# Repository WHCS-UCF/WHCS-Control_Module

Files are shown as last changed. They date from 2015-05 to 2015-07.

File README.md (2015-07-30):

# WHCS Control Module Design

The EAGLE source files for WHCS' control module.

## Requirements
EAGLE

## Board Front
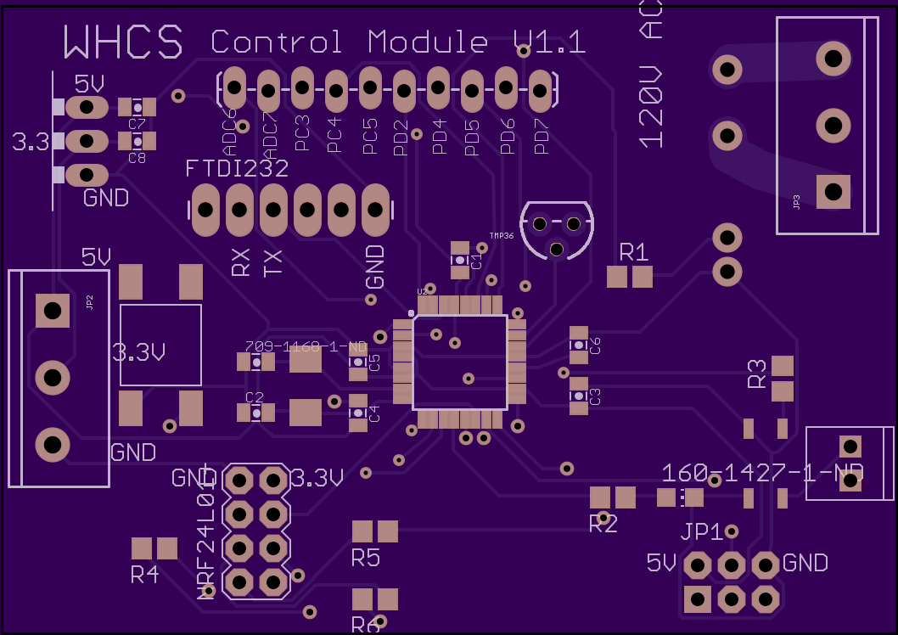
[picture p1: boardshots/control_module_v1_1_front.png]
Board Front


## Board Back
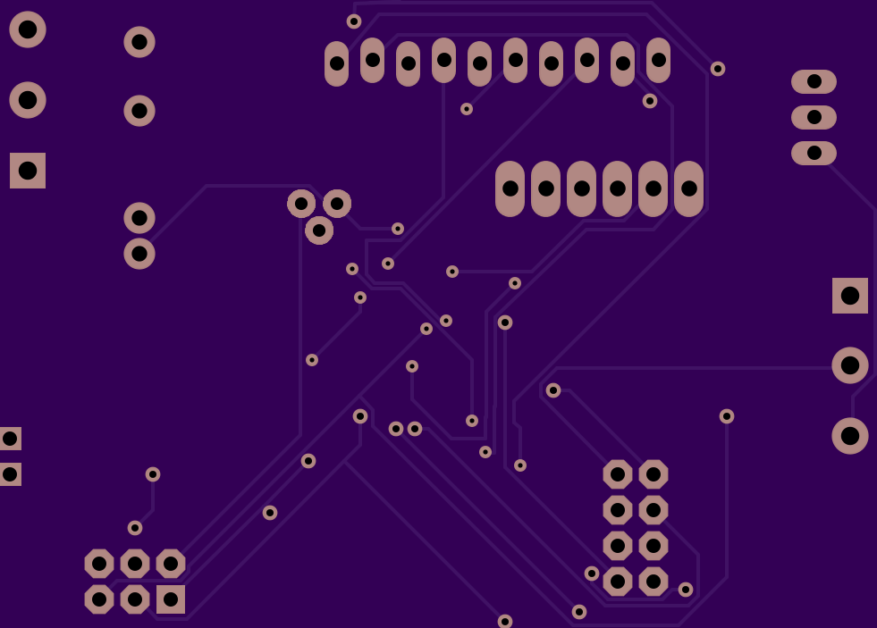
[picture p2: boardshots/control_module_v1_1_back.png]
Board Back


### Author
Jimmy Campbell<br/>
*Computer Engineer*

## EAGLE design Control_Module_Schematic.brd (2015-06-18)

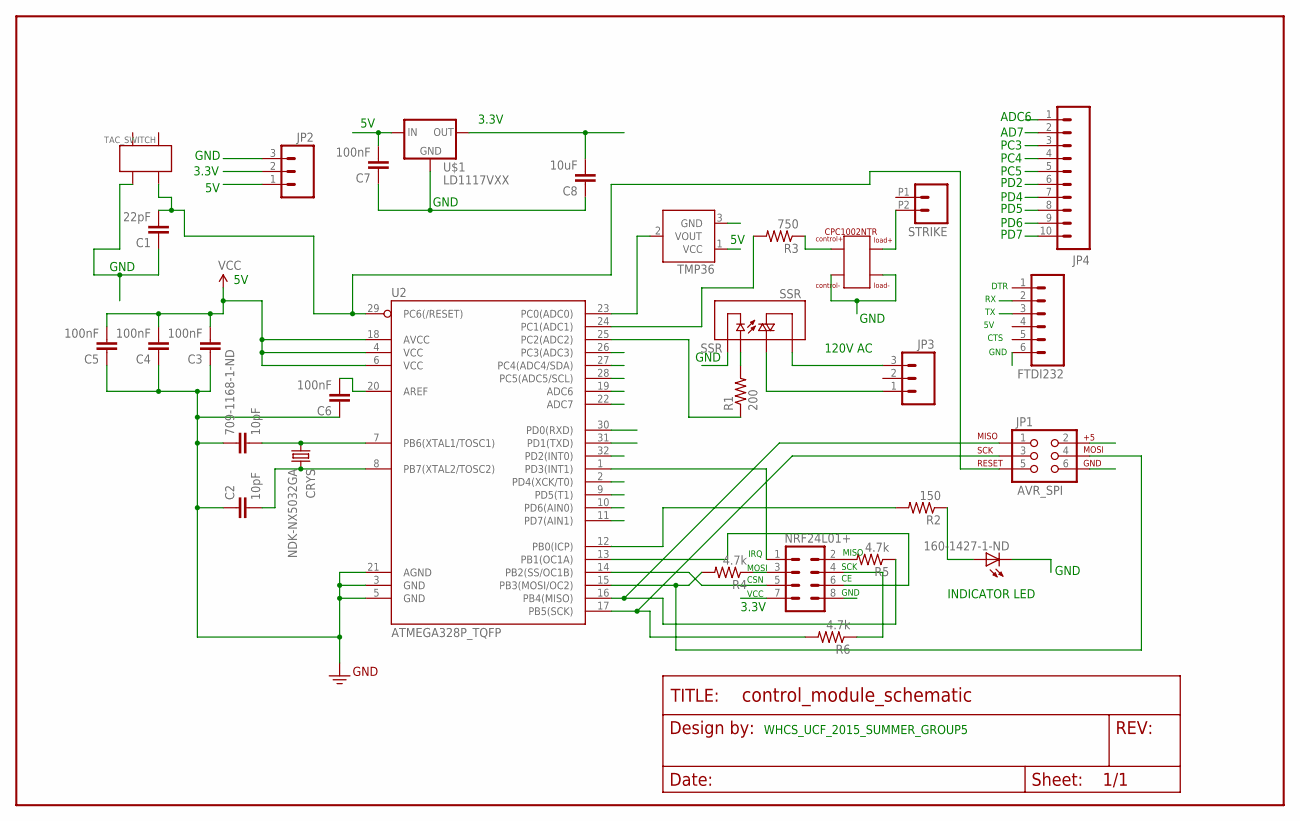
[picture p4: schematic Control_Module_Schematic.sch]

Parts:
160-1427-1-ND: LEDCHIP-LED0805; CHIP-LED0805
709-1168-1-ND: 10pF; 0805-CAP
C1: 22pF; 0805-CAP
C2: 10pF; 0805-CAP
C3, C4, C5, C6, C7: 100nF; 0805-CAP
C8: 10uF; 0805-CAP
CPC1002NTR: CPC1002NTR; CPC1002N
CRYS: NDK-NX5032GA; CRYS-5X3.2
FRAME1: FRAME-LETTERNO_PACKAGE; DUMMY
FTDI232: M06LONGPADS; 1X06_LONGPADS
JP1: AVR_SPI; 2X3-NS
JP2, JP3: M03-SCREW-5MM; SCREWTERMINAL-5MM-3
JP4: M10LOCK_LONGPADS; 1X10_LOCK_LONGPADS
NRF24L01+: M04X2; 2X4
R1: 200; R0805
R2: 150; R0805
R3: 750; R0805
R4, R5, R6: 4.7k; R0805
SSR: SSR; RELAY-S116S02F
STRIKE: M022.54MM_SCREWTERM; 1X02_2.54_SCREWTERM
TAC_SWITCH: TACTILE_SWITCH; TAC_SWITCH_GULL_WING
TMP36: TMP36TO-92-KIT; TO-92-KIT
U2: ATMEGA328P_TQFP; TQFP32-08
U$1: LD1117VXX; 78XXL

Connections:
3.3V: C8.2, JP2.2, NRF24L01+.7, U$1.OUT
5V: C3.2, C4.2, C5.2, C7.2, JP1.2, JP2.1, TMP36.1 (VCC), U2.4 (VCC), U2.6 (VCC), U2.18 (AVCC), U$1.IN
ADC6: JP4.1, U2.19 (ADC6)
ADC7: JP4.2, U2.22 (ADC7)
GND: 160-1427-1-ND.C, 709-1168-1-ND.1, C1.1, C2.1, C3.1, C4.1, C5.1, C6.1, C7.1, C8.1, CPC1002NTR.P$1, CPC1002NTR.P$4, FTDI232.6, JP1.6, JP2.3, NRF24L01+.8, SSR.P$4 (-), TAC_SWITCH.P$2, TMP36.3 (GND), U2.3 (GND), U2.5 (GND), U2.21 (AGND), U$1.GND
unnamed: NRF24L01+.5, U2.14 (PB2(SS/OC1B))
unnamed: JP1.1, R5.1, U2.16 (PB4(MISO))
unnamed: JP1.4, R4.2, U2.15 (PB3(MOSI/OC2))
unnamed: JP1.3, R6.2, U2.17 (PB5(SCK))
unnamed: NRF24L01+.1, U2.1 (PD3(INT1))
unnamed: NRF24L01+.6, U2.13 (PB1(OC1A))
unnamed: TMP36.2 (VOUT), U2.23 (PC0(ADC0))
unnamed: R1.2, SSR.P$3 (+)
unnamed: R1.1, U2.25 (PC2(ADC2))
unnamed: JP3.3, SSR.P$1 (T1)
unnamed: JP3.1, SSR.P$2 (T2)
unnamed: R3.2, U2.24 (PC1(ADC1))
unnamed: CPC1002NTR.P$2 (CONTROL+), R3.1
unnamed: 709-1168-1-ND.2, CRYS.P$1 (1), U2.7 (PB6(XTAL1/TOSC1))
unnamed: C2.2, CRYS.P$2 (2), U2.8 (PB7(XTAL2/TOSC2))
unnamed: R2.2, U2.12 (PB0(ICP))
unnamed: 160-1427-1-ND.A, R2.1
unnamed: CPC1002NTR.P$3, STRIKE.P2 (2)
unnamed: NRF24L01+.3, R4.1
unnamed: NRF24L01+.2, R5.2
unnamed: NRF24L01+.4, R6.1
unnamed: C6.2, U2.20 (AREF)
unnamed: C1.2, JP1.5, TAC_SWITCH.P$4, U2.29 (PC6(/RESET))
PC3: JP4.3, U2.26 (PC3(ADC3))
PC4: JP4.4, U2.27 (PC4(ADC4/SDA))
PC5: JP4.5, U2.28 (PC5(ADC5/SCL))
PD2: JP4.6, U2.32 (PD2(INT0))
PD4: JP4.7, U2.2 (PD4(XCK/T0))
PD5: JP4.8, U2.9 (PD5(T1))
PD6: JP4.9, U2.10 (PD6(AIN0))
PD7: JP4.10, U2.11 (PD7(AIN1))
RXD: FTDI232.3, U2.30 (PD0(RXD))
TXD: FTDI232.2, U2.31 (PD1(TXD))

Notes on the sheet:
IRQ
MOSI
CSN
VCC
MISO
SCK
GND
120V AC
3.3V
INDICATOR LED
DTR
CTS
ADC6
AD7
PC3
PC4
PC5
PD2
PD4
PD5
PD6
PD7
WHCS_UCF_2015_SUMMER_GROUP5

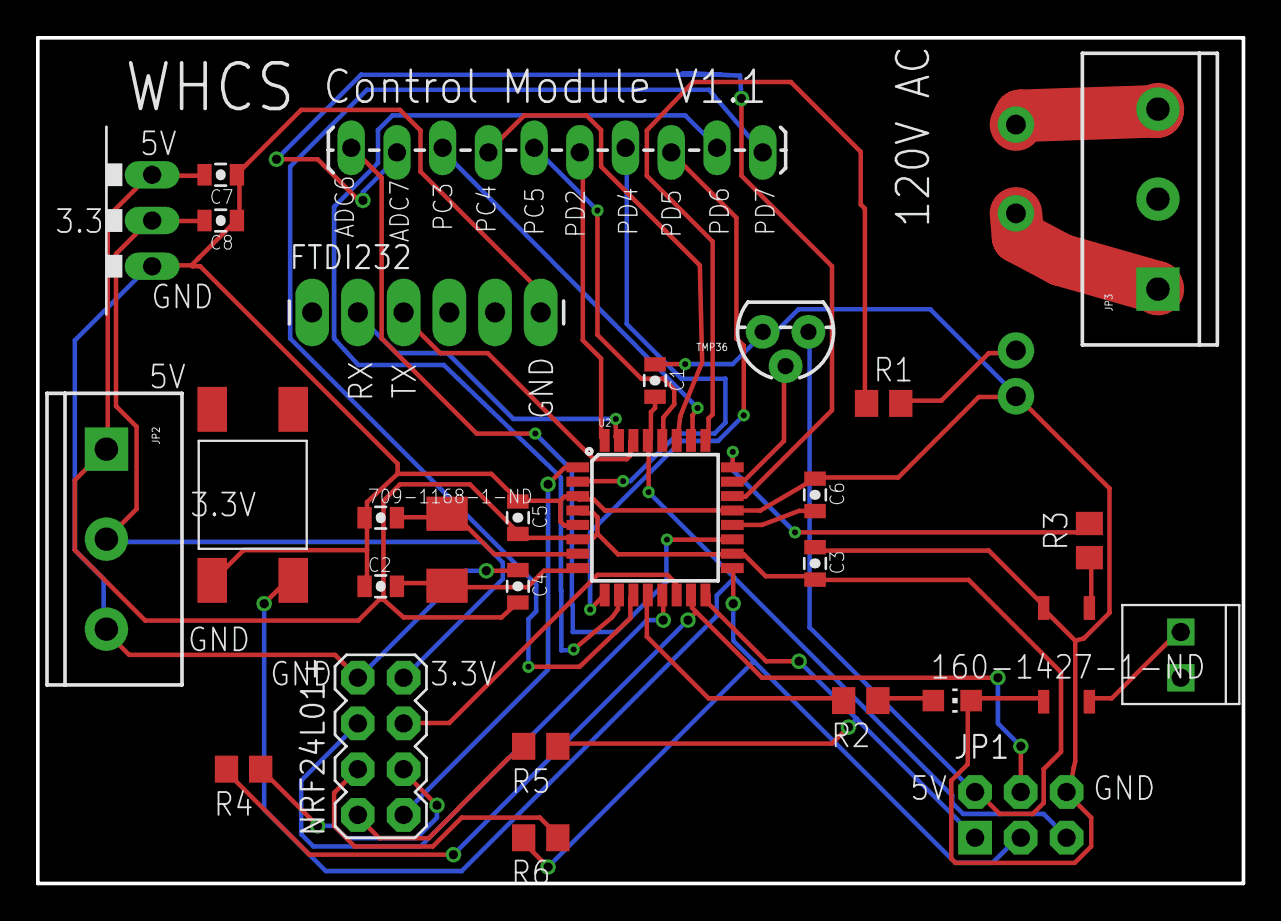
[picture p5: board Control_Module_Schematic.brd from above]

Board: 2 copper layers, 67.0 x 47.0 mm, 31 parts (0 on the bottom side), 38 nets.

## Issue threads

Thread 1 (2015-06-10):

Electronic strike solid state relay

jimmypc92, 2015-06-10:
The SSR for the electronic strike is connected to the ADC6 pin on the ATMEGA328P. This pin is not capable of providing output. The workaround for this is directly soldering a jumper wire on the board to the resistor that is connected to the ADC6 pin.

This is a big issue and should be fixed before any more orders are made.

Closed 2015-06-10.

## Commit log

2015-05-22 Made the layout for the board.
    [Control_Module_Schematic.brd, Control_Module_Schematic.sch]
2015-05-26 Board status when first submitted.
    This is the way the board was when first submitted to Oshpark for an
    initial run.
    [Control_Module_Schematic.brd, Control_Module_Schematic.sch]
2015-05-29 fixed drc fail. Two vias were too close together at the top right of the mcu
    [Control_Module_Schematic.brd, Control_Module_Schematic.sch]
2015-06-10 Changed the pin that controls the door strike
    [Control_Module_Schematic.brd, Control_Module_Schematic.sch]
2015-06-10 Enhanced crystal footprint
    Also did some changing of the route placements to make them have better
    spacing.
    Added documentation to the TPlace layer to show how the power should be
    connected.
    [Control_Module_Schematic.brd, Control_Module_Schematic.sch]
2015-06-10 Did some route optimization
    [Control_Module_Schematic.brd]
2015-06-10 Connected the FTDI232 UART chip's GND to GND
    [Control_Module_Schematic.brd, Control_Module_Schematic.sch]
2015-06-11 AC solid state relay pin change
    The AC SSR is now controlled by pc2 from the atmega328. The previous pin
    used to control it ADC7 was not capable of producing output and it has
    been rerouted to the breakout header.
    [Control_Module_Schematic.brd, Control_Module_Schematic.sch]
2015-06-17 Added tactile switch for reset
    Also did some manual routing optimizations
    [Control_Module_Schematic.brd, Control_Module_Schematic.sch]
2015-06-18 Final changes before placing oshpark 2nd order.
    [Control_Module_Schematic.brd]
2015-07-30 Add boardshots and readme.md

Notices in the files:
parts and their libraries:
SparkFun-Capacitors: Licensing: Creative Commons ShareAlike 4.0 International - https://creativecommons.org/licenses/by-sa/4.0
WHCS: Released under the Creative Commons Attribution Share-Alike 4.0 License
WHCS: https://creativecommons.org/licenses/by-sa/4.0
